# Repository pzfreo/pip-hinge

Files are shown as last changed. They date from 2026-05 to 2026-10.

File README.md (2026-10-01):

# pip-hinge

A parametric print-in-place piano hinge in [build123d](https://github.com/gumyr/build123d),
designed for clamshell cases.

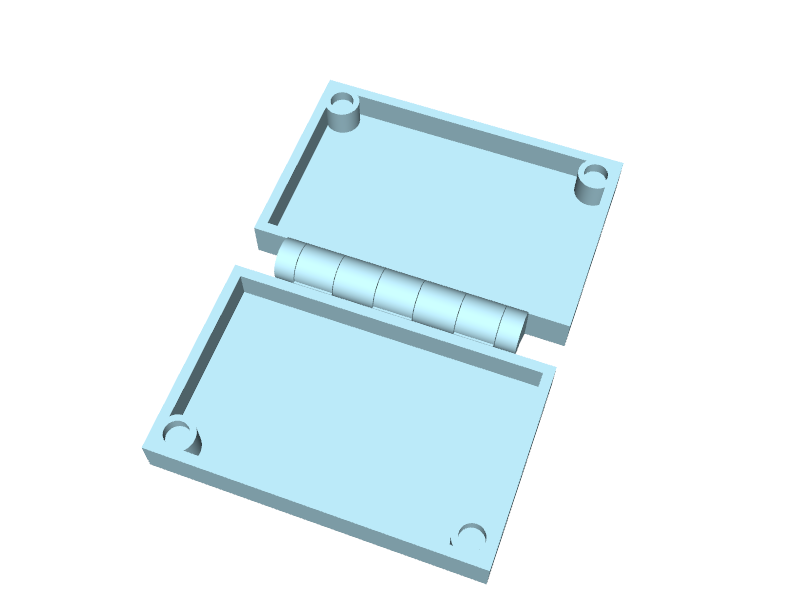
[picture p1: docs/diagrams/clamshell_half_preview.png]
clamshell with HALF knuckle and corner magnet pockets, flat-open print orientation


Start with four main inputs; the [parameter table](#parameters) covers the remaining fit and geometry controls.

```python
from pip_hinge import Knuckle, PinStyle, PrintInPlaceHinge

hinge = PrintInPlaceHinge(
    case_h        = 10,             # case wall height (mm)
    hinge_length  = 60,             # total hinge length along the axis (mm)
    stations      = 6,              # alternating tab count (even, ≥ 2)
    knuckle       = Knuckle.FULL,   # FULL = "bump on top", no ramp needed
)
base_leaf, lid_leaf = hinge.cylinder_side, hinge.pin_side
```

The default pin has 45° conical tips. Choose `PinStyle.ROUNDED` or the
experimental `PinStyle.BRIDGED` with the `pin_style` argument when needed.

`PrintInPlaceHinge` is a build123d `Compound` with two labelled children,
one per leaf:

- **`cylinder_side`** — the leaf whose knuckle tabs carry the bores;
- **`pin_side`** — the leaf with the end caps and the captured pin.

(Internally these are abbreviated *cs* and *ps*.) Each child is a `Compound`,
because a bare leaf can be several solids — see `mounting_flat` below.

`make_hinge(HingeParams(...))` builds the same thing from a reusable
parameter value.

### Where the hinge comes out

The hinge is built flat-open, in print orientation, ready to fuse into a case
whose walls stand on the bed:

- bed at **Z = 0**, wall top at **Z = `case_h`**;
- hinge axis along **Y** through X = 0, Z = `case_h + pivot_z_offset`;
- `cylinder_side` reaches X = +`hinge.leaf_width`, `pin_side` X = −`hinge.leaf_width`
  — those outer faces are where the two case back walls go;
- Y spans ±`hinge_length / 2`.

So for a base whose back wall's outer face is at X = x0, place the leaves
(build123d children are relative to their parent, so move the leaves
themselves, not the hinge):

```python
from build123d import Pos

at = Pos(x0 - hinge.leaf_width, y_centre, 0)
base = base + at * hinge.cylinder_side
lid = lid + at * hinge.pin_side
```

### Joints

`cylinder_side.joints["pivot"]` is a `RevoluteJoint` on the hinge axis and
`pin_side.joints["pivot"]` a matching `RigidJoint`, so the hinge can be swung
in an assembly view (0° = flat-open as printed, 180° = closed):

```python
hinge.cylinder_side.joints["pivot"].connect_to(hinge.pin_side.joints["pivot"], angle=180)
```

Each leaf also has a `"mount"` `RigidJoint` at the bottom centre of its outer
face (X = ±`leaf_width`, Y = 0, Z = 0), axes aligned with the hinge frame. To
attach the hinge to a case wall with joints instead of `Pos`:

```python
from build123d import Location, RigidJoint

RigidJoint("hinge", base, Location((x0, y_centre, 0)))    # back-wall outer face, bottom centre
base.joints["hinge"].connect_to(hinge.cylinder_side.joints["mount"])
hinge.cylinder_side.joints["pivot"].connect_to(hinge.pin_side.joints["pivot"], angle=0)
base = base + hinge.cylinder_side                         # leaves are now in place
lid = lid + hinge.pin_side
```

## In context: a flat-open clamshell with HALF knuckle

Built by [`examples/clamshell.py`](https://github.com/pzfreo/pip-hinge/blob/main/examples/clamshell.py) — case_h = 10mm,
80 × 50 mm footprint, 60 mm hinge with `Knuckle.HALF`, plus four 6 × 3 mm
corner magnet pockets to latch the case shut. Both halves print as one
piece in the orientation shown. The example also emits a bare HALF/FULL
variant (no magnets) for reference.

## Quick start

Install version **0.3.0** from [PyPI](https://pypi.org/project/pip-hinge/)
with `uv add "pip-hinge>=0.3.0"`. Earlier releases do not include `PinStyle`
or `FitProfile`. In a checkout, install it for development with:

```bash
uv venv
uv pip install -e .
```

Then in your build123d code:

```python
from pip_hinge import Knuckle, PrintInPlaceHinge

hinge = PrintInPlaceHinge(case_h=10, hinge_length=60, knuckle=Knuckle.FULL)
base = my_base + hinge.cylinder_side
lid = my_lid + hinge.pin_side
```

To run the included examples from a checkout:

```bash
uv run python examples/clamshell.py          # writes clamshell_{full,half,small,magnets}.{step,stl}
uv run python examples/hinge_only.py         # writes the bare hinge_{full,half}.{step,stl}
uv run python examples/conical_test_print.py --fit tighter  # two-size print plate with tighter fit
```

## Geometry at a glance

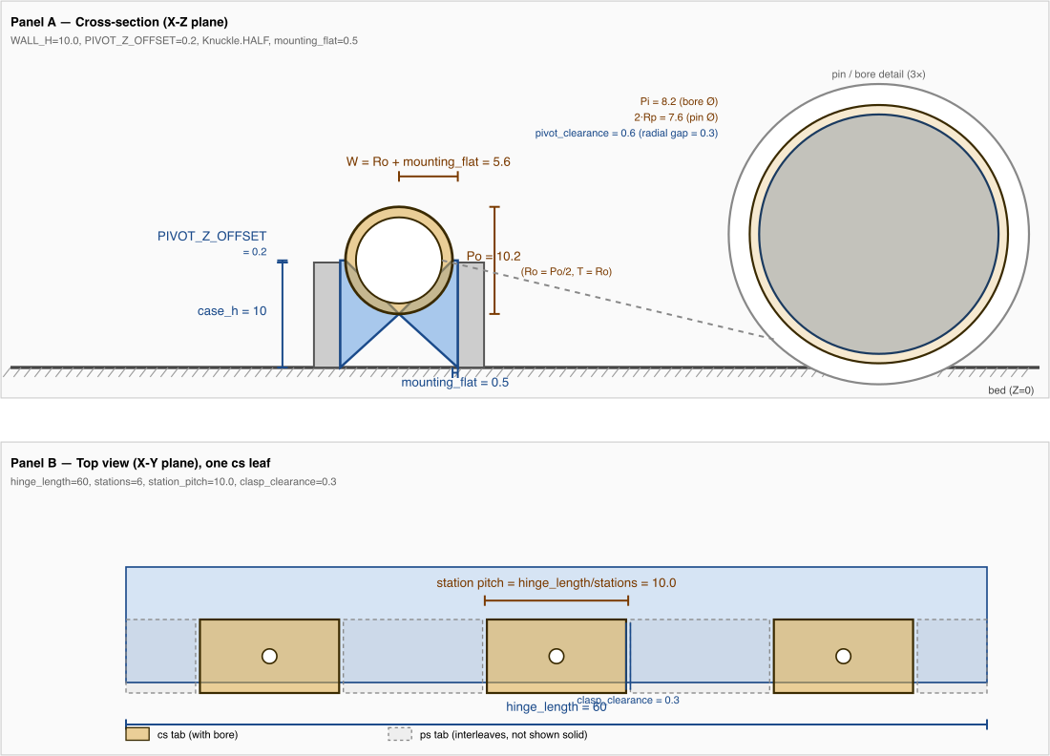
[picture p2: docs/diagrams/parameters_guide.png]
parameters guide


Cross-section (Panel A) shows the spatial parameters: `case_h` (wall
height), `pivot_z_offset` (extra lift), `mounting_flat` (flat past the
disc edge), plus the derived `Po`/`Ro`/`T`/`W` and the pin/bore inset.
Top view (Panel B) shows `hinge_length`, `stations`, derived
station pitch (`hinge_length / stations`), and `clasp_clearance` between tabs.

## Knuckle sizes

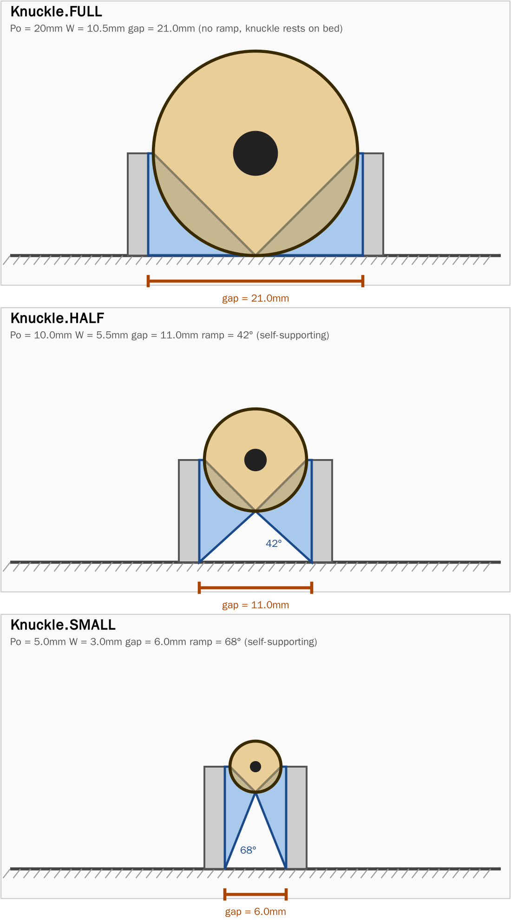
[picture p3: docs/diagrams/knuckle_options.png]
knuckle options


| `knuckle` | knuckle diameter | ramp | gap between case walls (flat-open) |
| --- | --- | --- | --- |
| `Knuckle.FULL` | `2 × (case_h + pivot_z_offset)` | none — rests on bed | `2 × (case_h + pivot_z_offset) + 2 × mounting_flat` |
| `Knuckle.HALF` | `case_h + pivot_z_offset` | 45° self-supporting teardrop | `case_h + pivot_z_offset + 2 × mounting_flat` |
| `Knuckle.SMALL`| `max((case_h + pivot_z_offset) / 2, 5 mm)` | ~25° from vertical (smaller knuckle → naturally steeper) | `max((case_h + pivot_z_offset) / 2, 5 mm) + 2 × mounting_flat` |

The knuckle diameter `Po` is sized to the lifted axis height
`case_h + pivot_z_offset`, and the flat-open gap between the case walls is
always `Po + 2 × mounting_flat` (= `2 × hinge.leaf_width`). For `case_h = 10`
with the defaults that is 21.4 mm (FULL), 11.2 mm (HALF) and 6.1 mm (SMALL).

See [docs/clamshell-integration.md](https://github.com/pzfreo/pip-hinge/blob/main/docs/clamshell-integration.md) for
mounting, orientation, multi-hinge layouts, and the closed-vs-open view.

## Parameters

The four primary inputs:

| Parameter | Default | Meaning |
| --- | --- | --- |
| `case_h` | (required) | Height in mm of the case wall each leaf attaches to |
| `hinge_length` | (required) | Total hinge length in mm along the rotation axis (Y) |
| `stations` | 6 | Even count of tab positions along Y, at least 2. Each end cap occupies half a position; 4, 6, 8, … are supported |
| `knuckle` | `Knuckle.FULL` | `FULL`, `HALF`, or `SMALL` — see the option table below |

`stations` counts alternating tab positions, not pin pairs or bored tabs.
For example, four stations make two bored cylinder-side tabs, one full
pin-side middle tab, and two half-width pin-side end caps. Any even count of
at least two is accepted; the usable count also depends on tab width.

Fit and pin options:

| Parameter | Default | Meaning |
| --- | --- | --- |
| `pin_style` | `PinStyle.CONICAL` | `CONICAL`: 45° tapered pin tips in matching tapered bores; `ROUNDED`: original hemispherical tips in round bores; `BRIDGED`: one continuous cylindrical pin in a teardrop-roof bore. Both revised bores released in one small clamshell print; the bridged hinge rocked noticeably |
| `knuckle_wall` | `None`  | Radial material thickness around the bore at its widest round section. `None` gives CONICAL at least 1.0 mm of modeled wall and grows the pin where station spacing permits. BRIDGED preserves at least 1.0 mm above its higher roof. Check the actual perimeter count in your slicer; set a value in mm to override |
| `mounting_flat` | 0.5 | Width in mm of the flat leaf strip beyond the knuckle where the case wall joins. At or below the resolved `pivot_clearance` the bare leaf can contain separate solids that join when fused to the wall |
| `pivot_clearance` | `None`  | Difference in mm between bore and pin diameters at the straight shank. The gap there is half this value; CONICAL also keeps that gap normal to its sloped tip. `None` selects 0.6 mm with STANDARD or 0.4 mm for small conical hinges with TIGHT |
| `pivot_z_offset`  | 0.2 | Lift of the hinge axis above the wall top. When closed, the lid then rests `2 × pivot_z_offset` above the base instead of meeting it on a zero-tolerance plane, so a high spot along the seam can't spring the front of the case open. Only the knuckle is raised — the leaves stay flush with the wall top. `0` disables it; must be less than the knuckle radius |
| `clasp_clearance` | `None`  | Gap in mm along Y between neighbouring tab faces. `None` selects the fit profile's value; an explicit value overrides it |
| `fit_profile` | `FitProfile.STANDARD` | `STANDARD` retains 0.3 mm radial and axial gaps. `TIGHT` gives small conical hinges the narrower gaps that worked in the earlier cylindrical-bore and the small shaped-bore trial |

### Tighter fit for small conical hinges

The [two-size conical test plate](https://github.com/pzfreo/pip-hinge/blob/main/examples/test_prints/README.md) printed and
released with the standard 0.3 mm gaps, but both lids rocked around the pin
and the smaller case also slid along the hinge axis. The
[tighter trial](https://github.com/pzfreo/pip-hinge/blob/main/examples/test_prints/tighter_fit/README.md) printed well on that
printer. Both printed plates used the earlier cylindrical bore. The
[new shaped-bore trial](examples/test_prints/shaped_bore_trial/README.md)
also released and felt good on that printer. Select the tighter gap values with:

```python
from pip_hinge import FitProfile, Knuckle, PrintInPlaceHinge

hinge = PrintInPlaceHinge(
    case_h=6, hinge_length=24, stations=4, knuckle=Knuckle.SMALL,
    fit_profile=FitProfile.TIGHT,
)
```

| Profile and geometry | Radial pin gap | Axial tab gap |
| --- | ---: | ---: |
| `STANDARD` (all hinges) | 0.3 mm | 0.3 mm |
| `TIGHT`: conical `SMALL`, barrel diameter ≤ 5.5 mm, station pitch ≤ 6 mm | 0.2 mm | 0.2 mm |
| `TIGHT`: conical `SMALL`, barrel diameter ≤ 5.5 mm, station pitch > 6 mm | 0.2 mm | 0.3 mm |
| `TIGHT`: other geometry | 0.3 mm | 0.3 mm |

Station pitch is `hinge_length / stations`. The straight-shank radial gap and
conical-tip normal gap are half of `pivot_clearance`, so 0.2 mm means
`pivot_clearance=0.4`. Passing
`pivot_clearance` or `clasp_clearance` explicitly overrides that part of the
profile. Fit still depends on the printer, material, and slicer settings;
try a small test print before committing to a large case. The successful
prints reported here were made on one **Bambu Lab P1S**. Material, nozzle
diameter, line width, layer height, and slicer profile were not recorded.
These results do not establish separate clearance recommendations for 0.4 mm
and 0.6 mm nozzles; use the [small Python trial](examples/shaped_bore_pair.py)
to check a different setup.

### Pin shapes and print tradeoffs

`CONICAL` uses short 45° pin tips and matching tapered bores. The small
shaped-bore trial released and felt good in one print. `ROUNDED` preserves the older
hemispherical tips and cylindrical bores. `BRIDGED` runs one continuous pin
through the whole hinge, which can resist pulling the leaves apart along the
axis, but its internal spans must print unsupported.

Conceptual conical, rounded, and bridged pin and bore sections

Cutaway of a continuous bridged pin

`BRIDGED` makes the printer span each bored tab with an unsupported pin.
The unsupported distance is approximately `hinge_length / stations +
clasp_clearance`: 5.3 mm for a 20 mm hinge with 4 stations, or 10.3 mm at
the 60 mm, 6-station defaults. The default `pivot_clearance` leaves only
0.3 mm of radial space between the printed pin and bore. Sagging plastic
can use up that space and fuse the hinge, even when the CAD solids are
separate. A tester reported that the earlier round bore roof settled onto
the pin and fused. The revised 45° teardrop roof released in one small
clamshell print, but that hinge was very loose and rocked around its pin.
In that size, the pointed roof leaves about 0.74 mm of modeled space above
the pin at its peak, even though the gap at the round sides is 0.3 mm.
The conical hinge from the same print felt much better. Check in the slicer
that the unsupported pin spans use bridge settings. Treat `BRIDGED` as an
experimental option when a continuous pin is needed; do not assume its
printed fit will match the conical hinge.

`ROUNDED` preserves the older pin and bore sizing. On a large barrel with
closely spaced stations, neighbouring rounded tips can meet inside a bore;
the library warns because the joined span may sag or fuse during printing.
The default `CONICAL` profile keeps an axial gap between its tips.

For 4 or more stations, the two middle tab types have the same width,
`hinge_length / stations − clasp_clearance`. Each end cap has half that width.
For example, a 20 mm hinge with 4 stations and the default gap has two
4.7 mm cylinder-side tabs, one 4.7 mm pin-side middle tab, and two 2.35 mm
end caps. The pin shank and tips extend into the bores beyond the middle
tab; that visible pin is wider than the tab itself.

The *shank* is the constant-diameter part of a pin between its pin-side tab
and its tapered or rounded tip. Three advanced settings change the shanks of
the `CONICAL` and `ROUNDED` pins. `pin_cyl_extra` adds to the station width to
give the middle shank length; it protrudes
`(pin_cyl_extra + clasp_clearance) / 2` past each
middle tab face. `pin_end_offset` sets how far an end shank protrudes past its
end cap face; its reach into the next bored tab is that value minus
`clasp_clearance`. `pin_short_cyl_factor × (hinge_length / stations)` is
the total end shank length, including the portion buried in the cap. These
settings do not affect the continuous `BRIDGED` pin. That pin runs the full
`hinge_length`; a shorter bridged pin is not currently parameterized.

### Geometry changes in 0.3

The default pin is now conical, with a matching tapered bore. It can use a wider bore than the original
rounded pin when station spacing leaves room for separate 45° tips; on
shorter hinges it uses a smaller bore to prevent those tips from joining.
`PinStyle.ROUNDED` retains the original pin tip profile and cylindrical bore.
The STANDARD tab gap is 0.3 mm measured between faces, with equal-width
middle tabs on both sides. Re-export existing designs and check the pin and
tab fit before relying on an older printed part.

## Validation

`PrintInPlaceHinge` / `make_hinge()` raise `ValueError` for hard geometric problems:
- non-positive `case_h`, `hinge_length`, or `mounting_flat`
- `stations < 2` or odd
- negative `pivot_z_offset`, or one not smaller than the knuckle radius
- bore Ø ≤ `pivot_clearance` (knuckle too small for the pivot clearance)
- `knuckle_wall` outside the knuckle radius
- invalid `pin_style` or clearances that leave no tab or pin material

And warns (`warnings.warn`) when:
- tab width `hinge_length / stations − clasp_clearance` drops below ~3 mm (too thin for FDM)

## Printing

Lay flat on the bed with the hinge axis along Y (parallel to bed).
Start with 0.2 mm layers and the part-cooling fan on. If adhesion needs a
brim, keep it clear of the hinge gaps. After printing, gently flex the leaves
to break the clearance gaps free.

For a first fit check of the current conical bore, use the
[small shaped-bore trial](examples/test_prints/shaped_bore_trial/README.md).
The [paired Python example](examples/shaped_bore_pair.py) generates the
conical and bridged cases used in the printed comparison and accepts gap
overrides for printer calibration.
The [earlier two-size plate](https://github.com/pzfreo/pip-hinge/blob/main/examples/test_prints/README.md)
documents the cylindrical-bore prints and their fit results.

- **FULL** knuckle body rests on the bed without supports. The optional
  `BRIDGED` pin still requires an unsupported bridge through each bore.
- **HALF** knuckle body has a self-supporting underside on valid sizes: it
  meets the disc tangentially at 45° and runs to the bed as a teardrop.
  The optional `BRIDGED` pin still needs a bridge test.

## How this was built

The build123d code, API design discussions, station-count generalisation,
self-supporting ramp, clamshell example, and documentation in this
repository were produced through a paired design session with
[Claude Code](https://claude.com/claude-code) (Anthropic's Claude Opus 4.7).
I drove the design decisions — what the API should look like, which
knuckle geometries to support, what trade-offs to accept — and Claude wrote
the code, generated the diagrams, ran the verifications, and opened the
PRs. The conversation is the source of truth for *why* the code looks the
way it does; the commit history reflects the steps.

The original FreeCAD geometry from r0berts provided the dimensional
starting point. The current pin profiles and fit defaults also include
changes described above. The Claude
collaboration is on the build123d port and the case-designer-facing API
built on top of it.

## Provenance

This is a port of **["Parametric print-in-place hinge. FreeCAD."](https://www.printables.com/model/1395662-parametric-print-in-place-hinge-freecad)**
by **[r0berts](https://www.printables.com/@r0berts_1183620)** on Printables,
licensed [CC BY 4.0](https://creativecommons.org/licenses/by/4.0/).

The original is a spreadsheet-driven FreeCAD model. This repository:

1. Translates the FreeCAD geometry into build123d Python via
   [fcd2b123d](https://github.com/pzfreo/fcd2b123d).
2. Reparameterises around four case-designer-facing inputs (`case_h`,
   `hinge_length`, `stations`, `knuckle`) with the original dimensional
   relationships derived under the hood.
3. Generalises the comb pattern (hardcoded 6 stations in the original) to
   any even number of stations ≥ 2, adds optional `Knuckle.HALF` and
   `Knuckle.SMALL` modes, and offers three pin profiles.

Per the CC BY 4.0 terms: design and dimensional relationships are
r0berts'; modifications are the build123d port, the four-input API, the
configurable station count, knuckle sizes, pin profiles, and fit defaults.
The original model's printer settings and extent of physical testing are
not documented in this repository.

## License

This work is licensed under [Creative Commons Attribution 4.0 International (CC BY 4.0)](https://creativecommons.org/licenses/by/4.0/),
matching the upstream Printables source. See [LICENSE](https://github.com/pzfreo/pip-hinge/blob/main/LICENSE).

When using or redistributing, please credit:

- **r0berts** — original FreeCAD design ([Printables](https://www.printables.com/model/1395662-parametric-print-in-place-hinge-freecad))
- **Paul Fremantle** (pzfreo) — build123d port, four-input parameterisation, station generalisation, and ramp option

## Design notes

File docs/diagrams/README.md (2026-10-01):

# Diagrams

Figures used in `docs/clamshell-integration.md` and the project README.
`pin_profiles.svg` compares the three pin and bore sections;
`bridged_pin.svg` shows the continuous pin along the hinge axis.

## Geometry diagrams (SVG → PNG)

```bash
python docs/diagrams/render_options.py        # → knuckle_options.svg
python docs/diagrams/render_closed_vs_open.py # → closed_vs_open.svg
python docs/diagrams/render_params.py         # → parameters_guide.svg
```

PNGs (used by markdown viewers that don't render SVG inline) via cairosvg:

```bash
uv run --with cairosvg python -c "
import cairosvg
for n in ['knuckle_options', 'closed_vs_open', 'parameters_guide']:
    cairosvg.svg2png(url=f'docs/diagrams/{n}.svg',
                     write_to=f'docs/diagrams/{n}.png',
                     output_width=1100)
"
```

## 3D model preview (clamshell_half_preview.png)

Rendered via [`build123d-mcp`](https://github.com/pzfreo/build123d-mcp)'s
`render_view` tool from the model in `examples/clamshell_magnets.step`:

```text
import_cad_file("examples/clamshell_magnets.step", "case")
render_view(objects="case", quality="high", azimuth=-25, elevation=25,
            save_to="docs/diagrams/clamshell_half_preview.png")
```

The MCP path uses VTK for clean shading; the equivalent matplotlib path
produces visible triangulation artifacts on curved surfaces, which is why
we use the MCP renderer instead.

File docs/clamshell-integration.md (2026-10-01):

# Integrating pip-hinge into a clamshell case

A practical guide for case designers who want to add a print-in-place piano
hinge to their build123d clamshell design.

## Scope

This guide covers symmetric clamshell cases (lid and base the same height),
printed as a single piece with the hinge already attached. The hinge is
treated as a separate piano hinge fused to the case back wall — not as the
case wall itself.

## The four inputs

```python
from pip_hinge import Knuckle, PinStyle, PrintInPlaceHinge

hinge = PrintInPlaceHinge(
    case_h        = 10,             # case wall height (mm)
    hinge_length  = 60,             # total hinge length along its axis (mm)
    stations      = 6,              # alternating tab count (even, ≥ 2)
    knuckle       = Knuckle.FULL,   # FULL = no ramp; HALF = 45° self-supporting ramp
)
cylinder_side, pin_side = hinge.cylinder_side, hinge.pin_side
```

Knuckle diameter, leaf width, and pin radius are derived from the first four
inputs. The conical pin is the default; choose `PinStyle.ROUNDED` for the
original hemispherical tips, or `PinStyle.BRIDGED` for one continuous pin
through every bored tab. `BRIDGED` is experimental: bridge sag can fuse the
pin to the bore despite the modeled clearance. Its revised teardrop roof
released in one small clamshell print, but that hinge rocked and felt much
looser than the conical one. These observations came from one Bambu Lab P1S;
other printer and nozzle combinations have not been validated. See the
[print trial](../examples/test_prints/shaped_bore_trial/README.md) before
printing a complete case.

The conical default uses a bore that follows the shank and 45° tips. The
knuckle wall and station spacing limit its widest radius while keeping at
least 1.0 mm of modeled material and separate tips. Check the actual
perimeter count in your slicer;
`knuckle_wall` sets the thickness explicitly.

The fit controls are:
`mounting_flat` (default 0.5 mm of flat past the disc edge for case-wall
attachment and clearance from the rotating barrel — the cs body fragments into multiple solids at this size but
they fuse into the case wall, see "Common gotchas" below), `pivot_clearance`
(difference between pin and bore diameters at the shank; the radial gap there
and normal gap along conical tips are half of it),
and `clasp_clearance` (the gap along Y between neighbouring tabs). With the
default `FitProfile.STANDARD`, both radial and axial gaps are 0.3 mm. See the
[tight-fit rule](../README.md#tighter-fit-for-small-conical-hinges) for the
0.2 mm gap values tested on small conical hinges with both the earlier
cylindrical bore and the newer shaped bore.

## Knuckle sizes

FULL vs HALF cross-section

Both panels above use `case_h = 10mm`, `mounting_flat = 0.5mm` (the default).

The knuckle is sized to the lifted axis height `case_h + pivot_z_offset`
(0.2 mm by default), and in every mode the flat-open gap between the case
walls is `Po + 2 × mounting_flat` (= `2 × hinge.leaf_width`).

### Knuckle.FULL  (Po = 2 × (case_h + pivot_z_offset))

The original print-in-place design. The knuckle diameter equals the full
closed-case height (lid + base stacked). When flat-open for printing, the
knuckle's bottom rests directly on the bed — no ramp, no support needed.
When closed, the back of the case shows a clean half-D bulge of full
case height.

Geometric properties:
- Knuckle protrudes `case_h + 2 × pivot_z_offset` *above* the wall top (the "bump on top").
- Gap between case walls when flat-open: `2 × (case_h + pivot_z_offset) + 2 × mounting_flat`.
- Leaf paddle bottom is on the bed; the leaf is a tall rectangle.

### Knuckle.HALF  (Po = case_h + pivot_z_offset)

A more compact knuckle, diameter equal to a single wall's height. Sits
mostly above the wall top, with the lower half overhanging into the gap.
A 45°-or-shallower ramp on each leaf supports the knuckle from below as
the print rises — the two leaves' ramps converge at the knuckle bottom.

Geometric properties:
- Knuckle protrudes `(case_h + pivot_z_offset) / 2 + pivot_z_offset` above the wall.
- Gap between case walls when flat-open: `case_h + pivot_z_offset + 2 × mounting_flat`.
- Leaf has a sloped lower-inner face (the ramp).

### Knuckle.SMALL  (Po = max((case_h + pivot_z_offset) / 2, 5 mm))

The smallest knuckle the geometry will produce: 1/4 of FULL with a 5 mm
absolute floor that keeps the bore + pin big enough to print reliably on
a 0.4 mm-nozzle FDM regardless of case height. For `case_h ≥ 10 mm` the
1/4-of-FULL ratio dominates; below that, the 5 mm floor kicks in.

Geometric properties:
- Knuckle protrudes `Po / 2 + pivot_z_offset` above the wall.
- Gap between case walls when flat-open: `max((case_h + pivot_z_offset) / 2, 5 mm) + 2 × mounting_flat`.
- Ramp **steeper** than HALF's at the same `mounting_flat`. Counterintuitive
  but true: a smaller knuckle puts the disc bottom higher above the bed,
  so the leaf's ramp (from outer-bottom corner to disc bottom) rises more
  per unit of horizontal travel. At default `mounting_flat = 0.5 mm`, the
  ramp sits at ~22° from vertical — comfortably self-supporting (versus
  HALF at ~48° which works in practice but is at the FDM-cooling limit).
- With the standard conical fit, the pin diameter for `case_h = 10 mm` is
  2.5 mm. The 5 mm floor preserves room for a printable bore wall on
  smaller cases.
- `FitProfile.STANDARD` uses a 0.3 mm gap between neighbouring tabs. Use
  `FitProfile.TIGHT` for the tested small conical sizes, or set
  `clasp_clearance` explicitly for your printer's fit.

## Closed vs flat-open

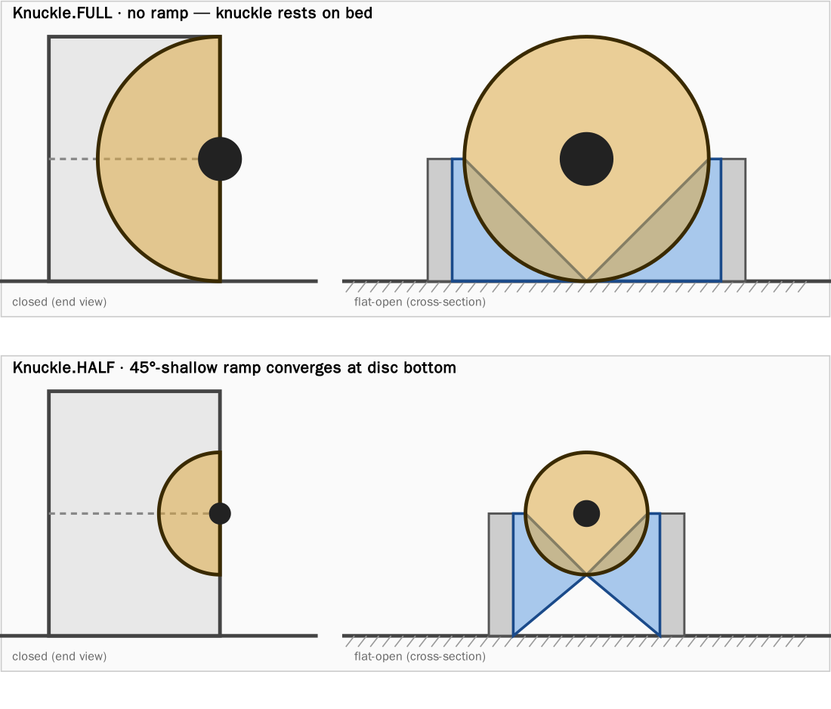
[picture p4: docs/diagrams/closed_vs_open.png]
closed and flat-open views


The closed-case profile shows the D-shaped bulge at the back. When flat-open
for printing, the same knuckle sits at axis
`Z = case_h + pivot_z_offset`, with the leaves extending from the axis down to
the bed.

## Coordinate convention

`PrintInPlaceHinge` comes out already placed for a flat-open case whose walls
stand on the bed:

- Bed at `Z = 0`; leaf tops flush with the wall top at `Z = case_h`.
- Hinge axis runs along **Y** through `(X = 0, Z = case_h + pivot_z_offset)`
  (`hinge.axis_z`).
- `cylinder_side` leaf extends to `X = +hinge.leaf_width`, `pin_side` to
  `X = −hinge.leaf_width`; the case back walls butt against these faces.
- Knuckle is centred on the axis, radius `Po/2`.
- Y range: `[−hinge_length/2, +hinge_length/2]`.

To put the hinge against a base whose back-wall outer face is at `X = x0`,
move the leaves (children are relative to their parent in build123d, so
moving the hinge itself does not move `hinge.cylinder_side`):

```python
from build123d import Pos

at = Pos(x0 - hinge.leaf_width, y_centre, 0)
base = base + at * hinge.cylinder_side
lid  = lid  + at * hinge.pin_side
```

## Stations

`stations` is the even number of tab positions along the rotation axis Y
(cs = cylinder side, ps = pin side). Two end caps each occupy half a
position. Any even count of at least 2 is accepted. Each full tab is
`hinge_length / stations - clasp_clearance` wide, so the STANDARD profile
leaves a 0.3 mm gap between neighbouring tab faces.

| stations | tabs | typical use |
| --- | --- | --- |
| 2 | 1 cs centred, 2 ps half-end-caps | tiny hinges (< 30mm)|
| 4 | 2 cs, 1 ps middle, 2 ps half-end-caps | small |
| 6 | 3 cs, 2 ps middle, 2 ps half-end-caps | default |
| 8, 10, … | scales up cleanly | long hinges |

Below a physical tab width of about 3 mm the tabs become thin for FDM
— a warning is emitted.

## One hinge or many?

Hinges do **not** need to run the entire case length. Multiple shorter
hinges along the back edge are usually better than one long one:

| Case back-edge length | Recommended hinges | Notes |
| --- | --- | --- |
| < 100 mm | 1 | Spans most or all of the back |
| 100–250 mm | 1 long or 2 shorter  | 2 shorter if the lid is heavy or thin |
| 250–450 mm | 2 | Position ~10–20 % in from each end |
| > 450 mm | 3+ | One centred, two ~15 % from the ends |

Multiple hinges **must be coaxial** — they all share the same hinge axis (Y
line). You position them at different Y offsets along that axis.

## Attaching the hinge to the case

Take the two leaves (`hinge.cylinder_side`, `hinge.pin_side`), position them on the case's back
edge, and boolean-union them into the case bodies.

For a clamshell with both halves coplanar on the bed during print:

```python
hinge = PrintInPlaceHinge(case_h=wall_h, hinge_length=back_edge_len,
                          knuckle=Knuckle.FULL)
base_body = base_body + hinge.cylinder_side
lid_body  = lid_body  + hinge.pin_side
```

If your assembly already uses build123d joints, place the leaves through
their named `"mount"` and `"pivot"` joints. Here `x0` is the base back wall's
outer X face and `y_centre` is the hinge centre along that wall:

```python
from build123d import Location, RigidJoint

RigidJoint("hinge", base_body, Location((x0, y_centre, 0)))
base_body.joints["hinge"].connect_to(hinge.cylinder_side.joints["mount"])
hinge.cylinder_side.joints["pivot"].connect_to(
    hinge.pin_side.joints["pivot"], angle=0
)
base_body = base_body + hinge.cylinder_side
lid_body = lid_body + hinge.pin_side
```

The leaf's outer face (at `X = hinge.leaf_width`) is where the case wall attaches.
`mounting_flat` controls the flat strip of leaf material past the disc edge
that the wall actually glues / fuses to — 0.5 mm is the default and is
deliberately below the `pivot_clearance` so the cylinder-side leaf fragments at the
disc-edge level. Those fragments still share their outer face with the case
wall and fuse cleanly on boolean union. Increase `mounting_flat` for a
larger glue surface at the cost of a wider gap between case halves.

### Multi-hinge variant

```python
hinge = PrintInPlaceHinge(case_h=wall_h, hinge_length=50, knuckle=Knuckle.FULL)
for y_centre in [-100, 0, 100]:
    base = base + Pos(0, y_centre, 0) * hinge.cylinder_side
    lid  = lid  + Pos(0, y_centre, 0) * hinge.pin_side
```

All hinges sit on the same axis (`Z = wall_h + pivot_z_offset`), at different Y positions.

## Print orientation

The natural orientation is **flat-open**: lid and base coplanar on the bed,
walls extending up, hinge axis at the top of the back walls.

- **Knuckle.FULL**: knuckle bottom rests on the bed at `Z = 0` (since
  `Po = 2 × (case_h + pivot_z_offset)` and the axis is at
  `Z = case_h + pivot_z_offset`). The outer barrel needs no ramp. The
  optional BRIDGED pin still has unsupported spans inside the bores.
- **Knuckle.HALF**: knuckle bottom hovers at `Z = (case_h + pivot_z_offset) / 2`. The 45°
  ramps on each leaf converge at the knuckle bottom, supporting it from
  below. Prints supportless at any case size, but you need to choose
  `mounting_flat` small enough that the ramp angle stays ≤ 45°.

In both cases the case walls provide structural support below the outer
hinge body. The optional BRIDGED pin still needs a printer-specific bridge
test inside the bore.

## Opening angle

The hinge mechanism rotates freely 360°. What limits actual opening is the
**case geometry**:

| Setup | Max angle  |
| --- | --- |
| Hinge axis right at the back wall top, on a table | 180° |
| Hinge axis offset back by `mounting_flat + Ro` | ~270° |
| Case picked up off the table | 360° |

For a clamshell that lies flat-open on a table, 180° is the natural max.

## Sealing & closure fit

- **Same wall height**: the symmetric clamshell assumes lid and base walls
  are equal. They meet at the midplane of the assembled case.
- **Wall edge tolerance**: leave 0.1–0.2 mm clearance between mating wall
  edges so they don't bind. Add a small chamfer (0.5 mm) on the outer top
  edges of both halves to hide the seam.
- **Latch / catch**: the hinge holds the back; for the front to stay
  closed, add a friction tab, snap catch, or magnet pocket. (Out of scope
  for this doc.)

## Worked example: small box, 1 hinge

See [`examples/clamshell.py`](../examples/clamshell.py) for the full
runnable script — it builds the same 80 × 50 × 10 mm clamshell for both
`Knuckle.FULL` and `Knuckle.HALF`, exporting to
`examples/clamshell_full.{step,stl}` and `examples/clamshell_half.{step,stl}`.

Sketch:

```python
from build123d import Align, Box, Compound, export_stl
from pip_hinge import Knuckle, PrintInPlaceHinge

CASE_H, CASE_W, CASE_D, WALL_T = 10, 80, 50, 2.5

def hollow_half(x_sign, leaf_outer_x):
    """Open-top box; back wall sits at X = leaf_outer_x on the hinge side."""
    x_min = x_sign * leaf_outer_x if x_sign > 0 else x_sign * (leaf_outer_x + CASE_D)
    align = (Align.MIN, Align.CENTER, Align.MIN)
    outer = Box(CASE_D, CASE_W, CASE_H, align=align).translate((x_min, 0, 0))
    inner = Box(CASE_D - 2*WALL_T, CASE_W - 2*WALL_T, CASE_H - WALL_T,
                align=align).translate((x_min + WALL_T, 0, WALL_T))
    return outer - inner

# pivot_z_offset (default 0.2 mm) raises the axis above the wall top
hinge = PrintInPlaceHinge(case_h=CASE_H, hinge_length=64, knuckle=Knuckle.FULL)

base = hollow_half(+1, hinge.leaf_width) + hinge.cylinder_side
lid  = hollow_half(-1, hinge.leaf_width) + hinge.pin_side
export_stl(Compound([base, lid]), "clamshell.stl")
```

Three things easy to get wrong:

- The case back wall sits at **X = `hinge.leaf_width`** (= `Ro + mounting_flat`),
  not at the hinge axis. The wall's inner face attaches to the leaf's outer face there.
- `base + lid` returns a `ShapeList` (one-shot boolean), not a `Compound` of
  two bodies. Wrap with `Compound([base, lid])` to keep them as separate
  print-in-place bodies.
- Pass the real wall height as `case_h` and leave `pivot_z_offset` to do
  the lift. Without the offset, the lid and base wall tops meet on a
  0-tolerance plane and any high spot anywhere along the seam springs the
  front jaw open by ~1 mm. The knuckle is sized to the lifted axis, so at
  `Knuckle.FULL` it still rests on the bed. Add corner magnet pockets
  if you want a positive latch (see `examples/clamshell.py`).

## Worked example: long box, 3 hinges

```python
case_w = 400
hinge_len_each = 60
hinge_y_centres = [-150, 0, 150]

base, lid = base_blank, lid_blank
hinge = PrintInPlaceHinge(case_h=wall_h, hinge_length=hinge_len_each,
                          knuckle=Knuckle.FULL)
for yc in hinge_y_centres:
    base = base + Pos(0, yc, 0) * hinge.cylinder_side
    lid  = lid  + Pos(0, yc, 0) * hinge.pin_side
```

The case back walls run continuously the full 400 mm; only the hinges are
segmented.

## Common gotchas

- **Wrong case_h**: `case_h` is the *wall height* of one case half, not the
  combined closed-case height. At FULL the knuckle works out to
  `2 × (case_h + pivot_z_offset)` in diameter — about twice the wall.
- **Too many stations**: doubling stations halves the station pitch. A tab
  width below ~3 mm may print poorly on FDM (a warning fires). For long hinges, keep
  stations at 6–10 and scale `hinge_length` instead.
- **Very small HALF knuckles**: as `case_h` shrinks, the bore can become too
  small for `pivot_clearance`; the constructor raises a clear error. Choose
  SMALL (with its 5 mm diameter floor) or FULL for tiny cases.
- **Increasing mounting_flat for HALF**: bigger mounting_flat means
  shallower ramp (still self-supporting). But the gap between case halves
  also grows. 1–2 mm is usually plenty for fusion.
- **Reducing mounting_flat below pivot_clearance**: at very small
  `mounting_flat` (< the resolved `pivot_clearance`, 0.6 mm with STANDARD)
  the leaf strip at X ∈ [Ro+Pc, W] collapses to zero/negative width — the bare hinge
  then comes back as N/2 + ~N/2 fragmented solids instead of 2.
  This is fine **as long as you fuse the hinge into a case**: each
  fragment shares its outer face with the case wall and fuses with it on
  boolean union. The case wall plays the role of the vanished leaf strip.
  `hinge.cylinder_side` / `hinge.pin_side` keep the fragments grouped by
  leaf, so you never need to sort `hinge.solids()` yourself.
- **Setting pivot_z_offset to 0**: gives zero design tolerance at the
  closed seam — any printed high spot then opens the front jaw. The 0.2 mm
  default (0.4 mm closed-case back gap) is a good starting point; magnets
  or finger pressure overcome that easily, and the case stops resting
  slightly open.

## Quick reference

For most clamshell cases:

```python
from pip_hinge import FitProfile, Knuckle, PinStyle, PrintInPlaceHinge

PrintInPlaceHinge(
    case_h          = wall_h,            # case wall height
    hinge_length    = back_edge_length,  # total length along the hinge axis
    stations        = 6,                 # default
    knuckle         = Knuckle.FULL,      # or HALF for a more compact knuckle
    pin_style       = PinStyle.CONICAL,  # 45-degree tips; ROUNDED or BRIDGED available
    mounting_flat   = 0.5,               # mm of flat past the disc for fusion (default)
    fit_profile     = FitProfile.STANDARD, # default; TIGHT for tested small conical hinges
    pivot_clearance = None,              # select from fit_profile; 0.6 here
    pivot_z_offset  = 0.2,               # default — axis lift above the wall top
    clasp_clearance = None,              # select from fit_profile; 0.3 here
)
```

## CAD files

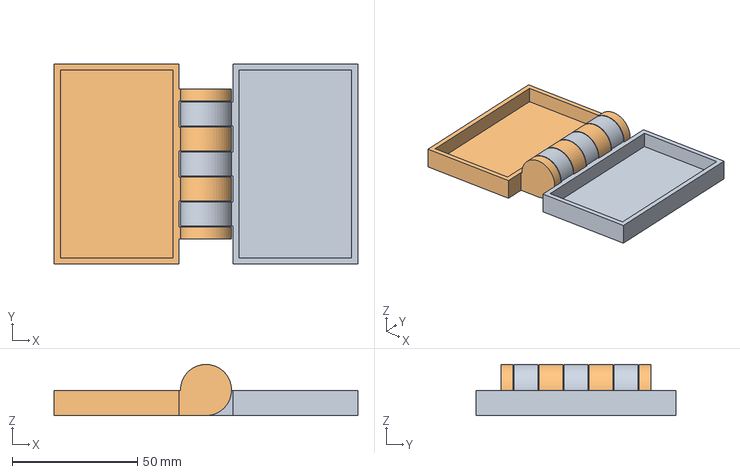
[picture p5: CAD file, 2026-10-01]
examples/clamshell_full.step
121.4 x 80.0 x 20.4 mm

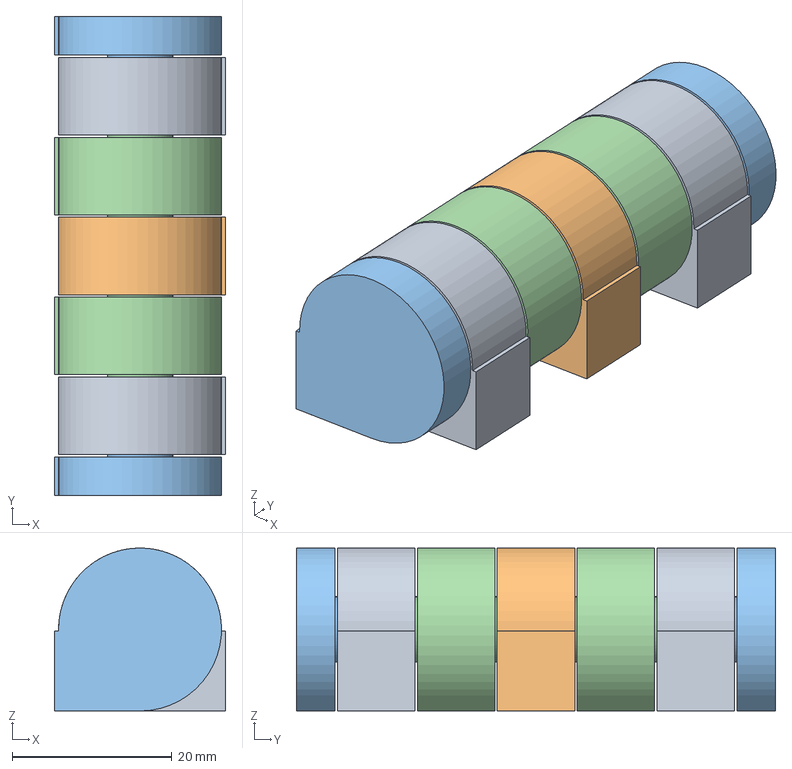
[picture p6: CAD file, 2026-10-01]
examples/hinge_full.step
21.4 x 60.0 x 20.4 mm
cylinder_side
pin_side

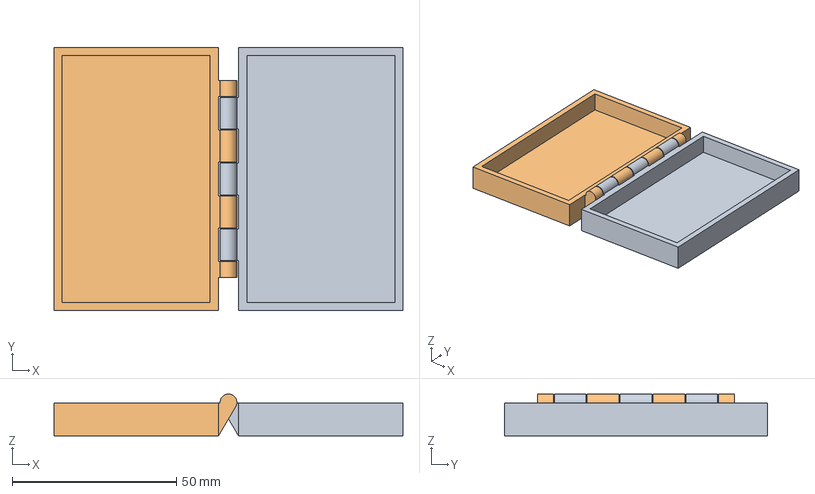
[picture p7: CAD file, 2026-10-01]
examples/clamshell_small.step
106.1 x 80.0 x 12.7 mm

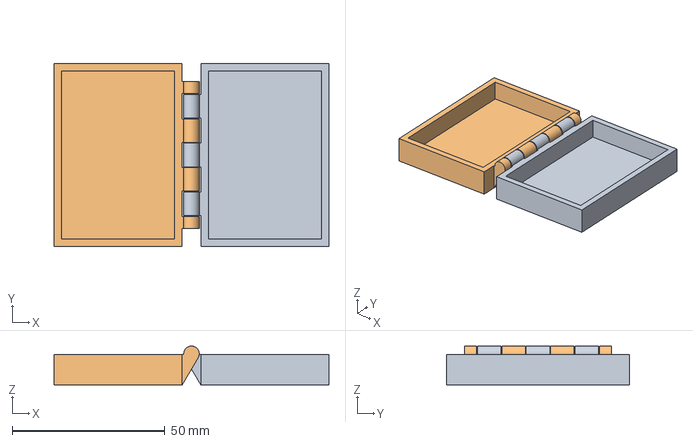
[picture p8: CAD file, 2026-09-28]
examples/test_prints/conical_clamshell_large.step
90.1 x 60.0 x 12.7 mm

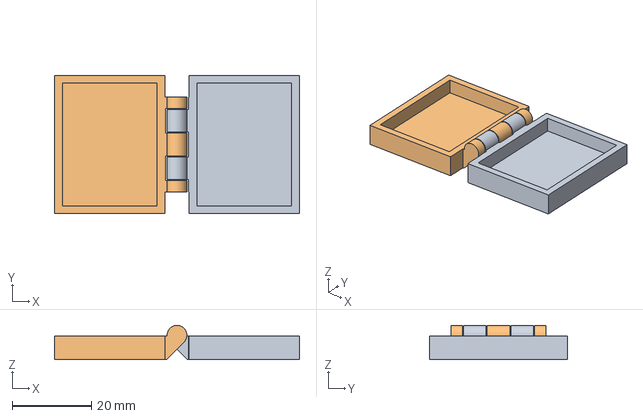
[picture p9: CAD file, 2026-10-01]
examples/test_prints/shaped_bore_trial/conical_shaped_bore_small.step
62.0 x 35.0 x 8.70 mm

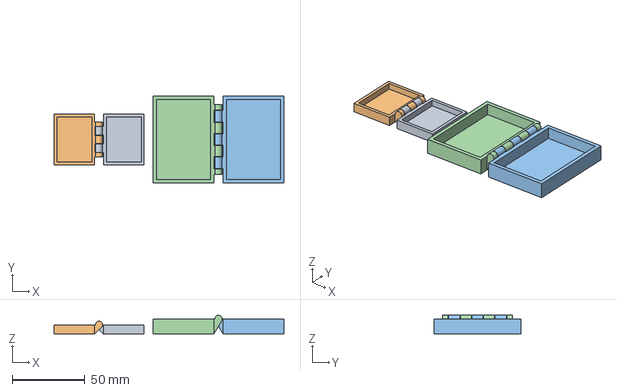
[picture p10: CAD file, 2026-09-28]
examples/test_prints/tighter_fit/conical_clamshell_pair.step
158.1 x 60.0 x 12.7 mm

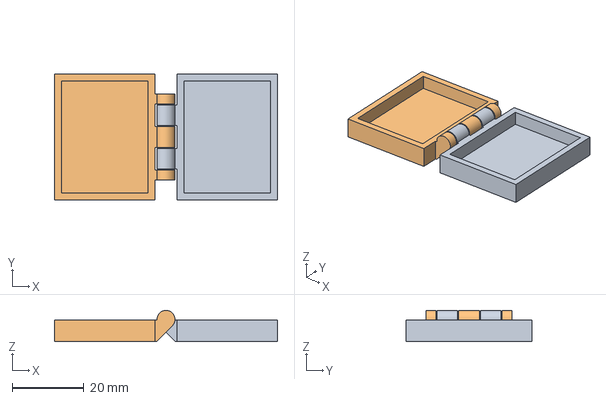
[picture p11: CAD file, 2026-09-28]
examples/test_prints/conical_clamshell_small.step
62.0 x 35.0 x 8.70 mm

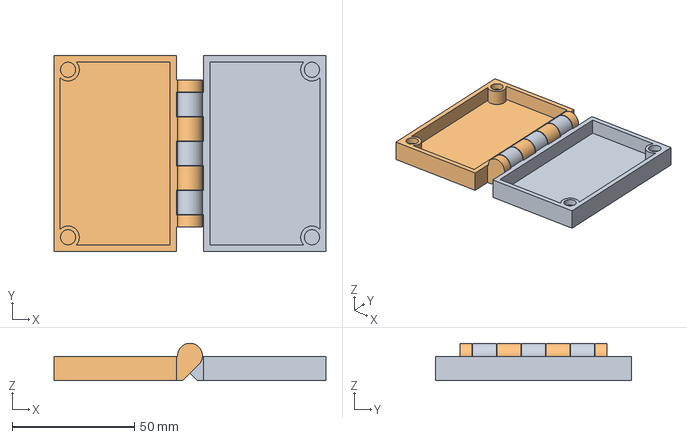
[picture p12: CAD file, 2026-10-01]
examples/clamshell_magnets.step
111.2 x 80.0 x 15.3 mm

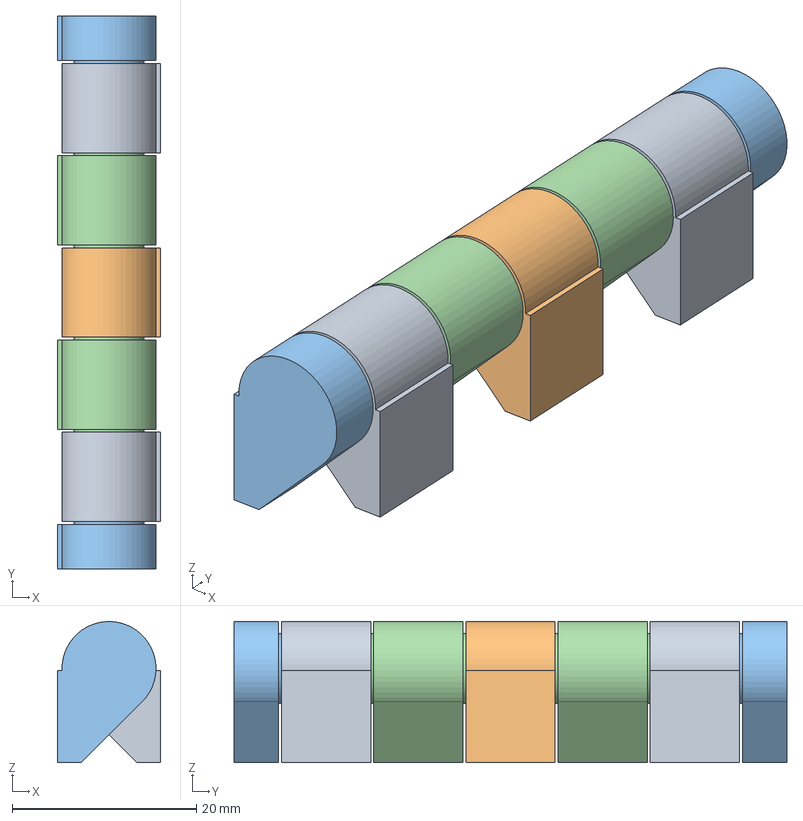
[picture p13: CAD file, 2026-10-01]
examples/hinge_half.step
11.2 x 60.0 x 15.3 mm
cylinder_side
pin_side

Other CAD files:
examples/test_prints/conical_clamshell_pair.step
examples/test_prints/tighter_fit/conical_clamshell_large.step
examples/test_prints/tighter_fit/conical_clamshell_small.step
examples/clamshell_half.step
examples/clamshell_full.stl
examples/clamshell_half.stl
examples/clamshell_magnets.stl
examples/clamshell_small.stl
examples/hinge_full.stl
examples/hinge_half.stl
examples/test_prints/conical_clamshell_large.stl
examples/test_prints/conical_clamshell_pair.stl
examples/test_prints/conical_clamshell_small.stl
examples/test_prints/shaped_bore_trial/conical_shaped_bore_small.stl
examples/test_prints/tighter_fit/conical_clamshell_large.stl
examples/test_prints/tighter_fit/conical_clamshell_pair.stl
examples/test_prints/tighter_fit/conical_clamshell_small.stl

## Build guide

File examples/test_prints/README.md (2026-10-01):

# Conical-pin clamshell test print

The [combined STL](conical_clamshell_pair.stl) contains two flat-open,
print-in-place clamshells, side by side with a 6 mm gap. Both use explicit
`PinStyle.CONICAL`, `Knuckle.SMALL`, and the library's default 0.3 mm axial
tab gap and 0.3 mm radial pin-to-bore gap.
The small knuckle is 5.0 mm in diameter on the smaller case and 5.1 mm on
the larger case.

Both cases have now been physically printed: the hinges released and worked,
but their rocking play was more than expected. The small case also slid along
the hinge axis. A [tighter fit trial](tighter_fit/README.md) subsequently
printed well: it reduces the radial pin gap on both cases and the axial tab
gap on the small case. Keep this original plate as the baseline for comparison.
These exported files retain the earlier cylindrical bore. The current code
uses a shaped conical bore; the [new small trial](shaped_bore_trial/README.md)
tested that change and printed well. The prints were on a **Bambu Lab P1S**.
The nozzle and layer values below are suggested starting settings, not a
record of the successful printer setup; material, nozzle diameter, line
width, layer height, and slicer profile were not captured.

| Case | Half footprint | Wall height | Hinge length | Stations | Flat-open footprint |
| --- | --- | ---: | ---: | ---: | --- |
| [Small](conical_clamshell_small.stl) | 35 × 28 mm | 6 mm | 24 mm | 4 | 62.0 × 35 mm |
| [Large](conical_clamshell_large.stl) | 60 × 42 mm | 10 mm | 48 mm | 6 | 90.1 × 60 mm |

The combined footprint is about **158.1 × 60 mm** before any brim. Import
the combined STL once, keep its open sides facing up and its flat bottoms on
the bed, and print without generated supports. Start at 0.2 mm layers with a
0.4 mm nozzle, and leave the slicer scale at 100%. Start without a brim; if
adhesion needs one, keep it at 2 mm or less and inspect the hinge gaps in the
slicer preview. The [STEP assembly](conical_clamshell_pair.step) is provided for CAD
inspection; use the STL for slicing.

After cooling, gently move each lid to free the print-in-place clearance.
Record whether each hinge releases, whether it rotates without binding, and
whether the lids close without a gap caused by the hinge. CAD checks cannot
predict all printer effects, so treat this as a fit test before printing a
larger case.

The command below exports the **current** geometry and will replace these
historical test files if run in this directory. To reproduce the original
exports exactly, run it from commit `502896f` instead.

From the repository root:

```bash
.venv/bin/python examples/conical_test_print.py
```

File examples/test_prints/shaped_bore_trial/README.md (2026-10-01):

# Shaped conical bore trial — printed

This small clamshell tests the revised conical bore. The bore follows the pin's
straight shank and 45° tip, leaving a 0.2 mm modeled gap normal to the cone.
The printed small case released and the hinge felt good. In the same print, a
small `BRIDGED` case with a teardrop-roof bore also released, but was very
loose and rocked around its pin. This is one print result, not a fit guarantee
for other sizes or printers. The [earlier tighter-fit
plate](../tighter_fit/README.md) also printed successfully; its
STL uses the original cylindrical bore and remains available for comparison.

The comparison used the same 24 mm, four-station SMALL hinge on both cases.
The conical case used `FitProfile.TIGHT` (0.2 mm radial and axial gaps); the
bridged case used `FitProfile.STANDARD` (0.3 mm radial and axial gaps). These
results came from one **Bambu Lab P1S**; material, nozzle diameter, line
width, layer height, and slicer profile were not recorded.
The teardrop roof leaves about 0.74 mm of modeled space above the bridged
pin at its peak, which helps explain the rocking despite the 0.3 mm gap at
the round sides.

The trial uses `Knuckle.SMALL`, a 24 mm hinge with four stations, and
`FitProfile.TIGHT`. Its case halves each measure 35 × 28 × 6 mm. Print the
[STL](conical_shaped_bore_small.stl) at 100% scale, flat on the bed with the
open sides up and generated supports off. Use a calibrated slicer profile;
the successful print does not establish nozzle-specific settings. Check the
bore and pin in the slicer preview before printing.
The [STEP file](conical_shaped_bore_small.step) is for CAD inspection.

In the slicer preview, check three regions before starting: the first-layer
gaps between moving parts must remain open; the conical tips must remain
separate inside each bored tab; and the bridged pin's unsupported spans must
use bridge toolpaths. The diagrams show CAD geometry, not actual slicer
toolpaths or measured prints.

After cooling, check that the hinge releases and rotates without binding.
Compare lid rocking and axial sliding against the earlier tighter-fit print.
Record printer, material, nozzle, line width, layer height, and slicer settings
alongside the result. A valid CAD clearance does not guarantee release.

Regenerate from the repository root:

```bash
python examples/conical_bore_trial.py
```

To reproduce **both** printed cases from Python, including the two dots that
mark the bridged base, run:

```bash
python examples/shaped_bore_pair.py
```

This writes individual STEP files and a 130 × 35 mm pair with a 6 mm gap in
the current directory: conical on the left, bridged on the right. The script
defaults to the printed gaps above; it does not change the library's default
fit settings.

If the pin fuses to its bore, try increasing only that case's radial gap by
0.05 mm, for example `--conical-radial-gap 0.25`. The script sets
`pivot_clearance` to twice the requested radial gap. If adjacent knuckle
faces fuse, increase that case's axial gap by 0.05–0.1 mm, for example
`--conical-axial-gap 0.25`. For the bridged case, inspect the unsupported
pin spans and bore roof in the slicer and check its bridge settings; more
clearance may release it but will add to its already noticeable play.
For a different printer or nozzle, treat these as starting CAD gaps and
calibrate with a small print. There is no validated 0.4 mm versus 0.6 mm
nozzle tolerance table from the available P1S prints.

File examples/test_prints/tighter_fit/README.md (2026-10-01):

# Tighter conical-hinge fit trial

This trial followed the [original plate](../README.md), which released but
had noticeable rocking around both pins. The small case also slid along the
hinge axis. Both tighter cases have now printed successfully. The
[combined STL](conical_clamshell_pair.stl) contains the same two case sizes,
both with `Knuckle.SMALL` and `PinStyle.CONICAL`. `pivot_clearance` changes
from 0.6 to 0.4 mm on both cases, so the modeled radial pin-to-bore gap
drops from 0.3 to **0.2 mm**. The small case's axial tab gap drops from
0.3 to **0.2 mm**; the large case keeps the proven **0.3 mm** axial gap.
These exported files use the earlier cylindrical bore. The current code
uses a shaped conical bore; the [new small trial](../shaped_bore_trial/README.md)
tested that change and also printed well. The successful prints were on a
**Bambu Lab P1S**; material, nozzle diameter, line width, layer height, and
slicer settings were not recorded.

| Case | Half footprint | Hinge length | Radial gap | Axial gap | Individual STL |
| --- | --- | ---: | ---: | ---: | --- |
| Small | 35 × 28 mm | 24 mm | 0.2 mm | 0.2 mm | [STL](conical_clamshell_small.stl) |
| Large | 60 × 42 mm | 48 mm | 0.2 mm | 0.3 mm | [STL](conical_clamshell_large.stl) |

The combined plate occupies about **158.1 × 60 mm** before any brim. To save
material, print the small case alone first. Keep the same material, slicer
settings, and orientation used for the original print; use 100% scale and no
generated supports. Inspect the pin gaps in the slicer preview. These two
prints supplied the evidence for `FitProfile.TIGHT`; try the small case first
when testing on a different printer.
The [combined STEP](conical_clamshell_pair.step) and individual STEP files
are for CAD inspection.

After cooling, compare the new small case against the original: does the
hinge release, rotate through its range without binding, and rock less when
the lid is lifted at its far edge? Check whether the small lid also slides
less along the hinge axis. A 0.2 mm modeled gap can still fuse on another
printer, so do not treat CAD validity or one successful setup as a guarantee.

The command below exports the **current** geometry and will replace these
historical test files if run in this directory. To reproduce the original
exports exactly, run it from commit `502896f` instead.

From the repository root:

```bash
.venv/bin/python examples/conical_test_print.py --fit tighter
```

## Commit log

2026-05-24 Initial: parametric print-in-place piano hinge
    Lifted from hinge-03.fcstd via fcd2b123d, with every sketch coordinate
    rewritten in terms of named HingeParams fields. No magic numbers in the
    geometry — all literals trace back to parameters or documented constants
    from the original FreeCAD design.
    Default parameters reproduce the hinge-03 geometry bit-for-bit:
    cylinder_side vol = 6060.7123 mm³ (matches FreeCAD reference)
    pin_side vol = 6728.8937 mm³ (matches FreeCAD reference)
    inter-leaf clearance = 0.3 mm everywhere (FDM print-in-place ready)
    Verified scaling works across:
    - 2× scale (80mm hinge)
    - chunky pivot (pivot_inner=8, larger pin/bore + thicker leaf)
    - tighter clas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
    [hinge_chunky.step, hinge_chunky.stl, hinge_default.step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]
2026-05-24 Add CC BY 4.0 license and attribution to r0berts
    The original design is "Parametric print-in-place hinge. FreeCAD."
    by r0berts on Printables (model 1395662), licensed CC BY 4.0. This
    build123d port is a derivative under the same license. Add LICENSE
    file with full attribution and update README + module docstring with
    the upstream link and credit.
2026-05-24 docs: clamshell-integration guide for case designers
    Covers sizing, single vs multiple coaxial hinges along the back edge,
    attachment via boolean fusion, print orientation, opening-angle limits,
    and worked examples for both small (1-hinge) and long (3-hinge) cases.
    Corrects an earlier mistaken assumption that a hinge must span the full
    case length — for longer cases, 2 or 3 shorter coaxial hinges are
    typically better than one long one (less warp risk during print, less
    inter-leaf fusion area, distributed load).
2026-05-25 Add self_support_ramp flag for clamshell flat-open printing (#1)
    * Add self_support_ramp flag for clamshell flat-open printing
    When a clamshell case lays the lid and base coplanar on the bed with
    the hinge between them, the knuckle becomes a horizontal cylinder
    whose bottom half overhangs into the gap. For small knuckles FDM
    bridges it cleanly; for larger ones or for reliable first-try prints,
    this is where supports start creeping in.
    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
2026-05-25 Replace HingeParams with four-input clamshell-focused API (#2)
    The previous API exposed the hinge's internal geometry parameters
    (hinge_height, hinge_width, hinge_thickness, pivot_inner, pivot_outer,
    clasp_width, ...), which is the right thing if you're building a
    standalone hinge but is too many knobs to reason about for the
    intended use case: bolting a print-in-place hinge to a clamshell.
    The new API takes four user-facing inputs:
    case_h case wall height (sets the hinge "scale")
    hinge_length total length along the hinge axis
    stations number of alternating cs/ps tabs (even, ≥ 2)
    knuckle Knuckle.FULL or Knuckle.HALF
    and derives everything else: knuckle diamete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
    [hinge_chunky.step, hinge_chunky.stl, hinge_default.step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]
2026-05-25 Add clamshell box examples + fix pocket polygon for small mounting_flat (#3)
    The new examples/clamshell.py builds a complete clamshell case (base + lid +
    integrated hinge) for both Knuckle.FULL and Knuckle.HALF, exporting STEP and
    STL. This is what users actually want as a worked example — the bare
    hinge_full/hinge_half files only demonstrate the hinge in isolation.
    Along the way, found and fixed a polygon-orientation bug in the cs pocket
    generator. The original FreeCAD code set Xo_cs (the pocket polygon's left
    edge) to Xi − W. At the original W=30 defaults, this gave Xo_cs ≈ −24,
    safely to the left of −Xi ≈ −6, so the tab-bypass jogs (which extend to
    −Xi) stayed inside the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
    [clamshell_full.step, clamshell_full.stl, clamshell_half.step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]
2026-05-25 docs: note Claude Code's role in the build123d port
    Adds a "How this was built" section between Printing and License,
    acknowledging that the API design discussions, code, diagrams, and
    docs in this repo were produced through a paired session with
    Claude Code. Reads as a credit, not a hand-off — design decisions
    were the user's; Claude wrote and verified the code.
2026-05-26 examples: pivot_z_offset=0.2 by default + magnet-pocket variant (#6)
    Print testing showed the bare-default clamshell rests slightly open with
    a ~1 mm front-jaw gap. Cause: lid and base wall tops meet on a
    zero-tolerance plane, so any high spot along the seam springs the case
    open under elastic tension. Raising the hinge axis 0.2 mm above the wall
    top gives a 2·δ = 0.4 mm intentional back gap that prevents incidental
    contact, and the case rests closed under its own tension.
    examples/clamshell.py
    - PIVOT_Z_OFFSET = 0.2 applied to all three exported variants
    - new add_corner_magnet_pockets() helper: cylindrical bosses pushed
    into the interior corners (tangent to the corner) s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
    [clamshell_full.step, clamshell_full.stl, clamshell_half.step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]
2026-05-26 Add Knuckle.SMALL — max(case_h/2, 5mm) (#7)
    * Add Knuckle.SMALL — max(case_h/2, 5mm), smallest reliably printable knuckle
    SMALL is 1/4 of FULL (Po = case_h/2) with a 5 mm absolute floor that keeps
    the bore + pin reliably printable on a 0.4 mm-nozzle FDM regardless of case
    height. For case_h ≥ 10 mm the 1/4 ratio dominates; below that, the floor
    kicks in (so a 5 mm-wall case still has a printable 5 mm-Ø knuckle).
    hinge.py
    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
    [clamshell_full.step, clamshell_full.stl, clamshell_half.stl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]
2026-05-26 clasp_clearance: size-aware default — 0.2 for SMALL, 0.4 for HALF/FULL (#8)
    Print test of clamshell_small showed too much axial play even though
    HALF/FULL with the same clearance feel fine. Reason: 0.4 mm gap is a
    larger fraction of the smaller hinge — the original r0berts FreeCAD
    design used 0.2 mm for the same reason.
    HingeParams.clasp_clearance is now Optional[float]; left as None
    (the default), _resolve() picks 0.2 for Knuckle.SMALL and 0.4 for
    HALF/FULL. Pass an explicit value to override either way (e.g. if a
    particular printer can't hold 0.2 mm without the tabs fusing, or if
    you want HALF tightened).
    No change for FULL/HALF users — they keep 0.4 as before. SMALL is the
    only AP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
    [clamshell_full.step, clamshell_half.step, clamshell_half.stl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]
2026-05-26 clasp_clearance: scale linearly with knuckle diameter (Po) (#10)
    You confirmed the print: SMALL with the size-aware 0.2 mm clasp clearance
    prints cleanly and the axial play feels right. The next step you asked
    for: drop the SMALL-vs-HALF/FULL binary and scale the clearance with the
    actual knuckle diameter instead.
    Previous formula:
    Cc = 0.2 if knuckle is SMALL else 0.4
    New formula:
    Cc = clamp(0.04 * Po, 0.2, 0.4)
    I.e. linear interpolation from 0.2 mm at Po = 5 mm (your tested SMALL
    case) to 0.4 mm at Po ≥ 10 mm (HALF/FULL territory at typical case_h).
    Clamped on both ends.
    Effect at common configs:
    case_h variant Po Cc (was) Cc (now)
    ----- ------- ---- -------- --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
    [clamshell_full.step, clamshell_half.step, clamshell_half.stl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]
2026-05-26 Make pivot_z_offset a first-class HingeParams parameter (#9)
    * Add pivot_z_offset as a first-class HingeParams parameter
    The empirical 0.2 mm lift was previously a leaky abstraction: it lived
    only as PIVOT_Z_OFFSET in the clamshell example, applied externally by
    passing case_h = WALL_H + PIVOT_Z_OFFSET. Every case designer had to
    re-discover the lift and re-apply it themselves.
    Make it a real parameter on HingeParams with the same default 0.2 mm.
    Internally:
    - The effective leaf height grows by pivot_z_offset so the bed-side
    end of the leaf still reaches the bed when the lifted axis is
    positioned at case_h.
    - The whole hinge body is translated up by pivot_z_offset so the
    le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
    [clamshell_full.step, clamshell_full.stl, clamshell_half.step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]
2026-05-26 examples/clamshell: give magnet pocket 0.1 mm radial clearance (#11)
    The previous code used pocket radius = magnet radius (zero clearance),
    which printed too tight for the magnets to slide in. 0.1 mm radial
    clearance (= 0.2 mm on diameter) is enough on a typical 0.4 mm-nozzle
    FDM — the issue was just needing it to be non-zero, not loose.
    Pocket now sized as ``MAGNET_OD/2 + POCKET_RADIAL_CLEARANCE`` with
    POCKET_RADIAL_CLEARANCE = 0.1 mm. Depth gets a matching 0.1 mm margin
    so the magnet sits flush without binding.
    Variable naming cleaned up while in there: MAGNET_R / MAGNET_D (where
    D meant "depth" but reads as "diameter" everywhere else) →
    MAGNET_OD, MAGNET_T, POCKET_R, POCKET_DEPTH, P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
    [clamshell_full.step, clamshell_half.step, clamshell_half.stl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]
2026-05-26 Make pip-hinge an installable Python package (#12)
    Before: pyproject.toml carried [tool.uv] package = false, so the project
    was a "script project", not an importable library. Downstream consumers
    either had to vendor hinge.py into their own tree (what gramel does) or
    set up a sys.path hack — neither of which lets pip install + import
    work cleanly.
    After: standard src-layout package. Anyone can:
    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
    [clamshell_full.step, clamshell_half.step, clamshell_half.stl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]
2026-06-25 Run the knuckle support ramp tangent to the disc (fixes meshing-side sag)
    The support ramp went from the wall foot straight to the bottom of the knuckle
    circle (0, -T) -- a RADIAL meeting, not a tangent. That leaves the circle's
    underside on the meshing side (the side with no wall) hanging past the contact
    point, so it sags when the print-in-place hinge is printed without supports
    (and prints partly fused, which made the hinge stiff and crack on first fold).
    Run the ramp up TANGENT to the circle instead: from the wall foot to the far
    tangent point, with the disc arc starting there. Each knuckle becomes a
    self-supporting teardrop that cradles the whole underside. SMALL/HALF use the
    tangent r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
2026-06-25 Enforce a self-supporting ramp: tangent >= 45° or raise (no sagging hinge)
    Adversarial review of the tangent fix found it regressed big-disc knuckles: the
    tangent is the steepest ramp that reaches the disc, so for HALF (Ro = case_h/2)
    it comes out ~36° from horizontal -- worse than the old ~43° and well under 45°,
    i.e. it sags. SMALL (small disc) is fine (>= 45°).
    Make it a hard contract: build a tangent ramp only when it is >= 45° from
    horizontal (self-supporting); otherwise raise ValueError naming the angle and
    suggesting Knuckle.SMALL or FULL. No configuration silently produces a hinge
    that needs support. FULL (disc on the bed) is unchanged.
    Sweep (case_h 4-50, all knuckles, mount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
2026-06-25 HALF: self-supporting teardrop knuckle, plus a test suite
    The HALF knuckle previously raised when its foot-anchored tangent ramp came
    out shallower than 45deg from horizontal (the disc is too big for the wall to
    reach steeply). Replace the raise with a teardrop: the support line meets the
    disc TANGENTIALLY on the meshing side at exactly the self-support angle and
    runs down to its own bed contact, so the disc's downward arc is cradled by a
    45deg face instead of left hanging. SMALL keeps the foot-anchored ramp; FULL
    still rests the disc on the bed. Refactored both leaves through one
    _leaf_profile() helper so the wall/underside/arc construction is shared.
    Add tests/ (the package had none): bui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
2026-06-25 Reject mounting_flat<=0; tighten build test to connectivity
    Adversarial review follow-ups:
    - mounting_flat=0 made W==Ro, a degenerate profile OCC rejected with a cryptic
    StdFail_NotDone. Reject it up front (<=0) with a clear ValueError. The 0.5
    default and all in-case use are unaffected.
    - test_builds_valid asserted only 'len(solids) >= 2', which the fragmented pile
    a too-small mounting_flat produces would pass. CASES all use
    mounting_flat=1.0 > pivot_clearance, so each leaf must be one connected body:
    assert exactly 2 solids. Add test_bare_hinge_fragments_below_pivot_clearance
    to LOCK the intentional sub-threshold fragmentation (documented in
    examples/clamshell.py:_split_hin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
2026-06-25 Release v0.3.0: self-supporting teardrop HALF knuckle + test suite
    Minor bump from 0.2.0: adds the HALF teardrop knuckle (tangent meet at
    45deg, self-supporting at any case_h), the first test suite (28 tests),
    and mounting_flat<=0 validation.
2026-06-26 Add PyPI OIDC Trusted Publishing workflow; slim the sdist
    Publish to PyPI on each GitHub Release via OIDC Trusted Publishing
    (pypa/gh-action-pypi-publish) -- no API token stored in the repo. A
    two-job build->publish split runs the publish step in a protected 'pypi'
    environment with id-token: write. workflow_dispatch allows the first
    publish to be triggered manually once the PyPI pending publisher exists.
    Also exclude examples/*.{stl,step} from the sdist: those are generated
    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
2026-09-27 Address #16 feedback: placed output, named leaves, joints, flush leaves
    - New PrintInPlaceHinge(Compound) class with keyword args, in the
    bd_warehouse style; make_hinge(HingeParams) now builds one.
    - Output is placed for a case on the bed: bed at Z=0, wall top at
    case_h, axis at case_h + pivot_z_offset, leaf outer faces at
    X = +/-leaf_width (exposed as hinge.leaf_width / hinge.axis_z).
    - Leaves are labelled children, hinge.cylinder_side / hinge.pin_side,
    grouped correctly even when a bare leaf fragments; replaces the
    example-only _split_hinge_by_side helper.
    - RevoluteJoint/RigidJoint "pivot" on the leaves (0 = flat-open,
    180 = closed).
    - pivot_z_offset now raises only the knuckl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
    [clamshell_full.step, clamshell_full.stl, clamshell_half.step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]
2026-09-27 Add "mount" RigidJoints on each leaf's outer face
    Lets a case wall with a joint place the cylinder-side leaf via
    connect_to, with the pin side following through the pivot joint.
2026-09-27 Include pivot_z_offset in knuckle sizing and wall-gap formulas
    The knuckle is sized to case_h + pivot_z_offset, so the flat-open wall
    gap is Po + 2 * mounting_flat. The README table and integration guide
    omitted the offset, and the SMALL gap formula was wrong outright
    (11 mm documented vs 6.1 mm built at case_h=10).
2026-09-27 Address hinge tab fit and add pin strategies
    Use equal-width alternating tabs and a measured axial clearance. Add conical, rounded, and experimental bridged pins with validation for wall thickness and overall length. Refresh docs, diagrams, generated examples, and packaging for 0.3.0.
    [clamshell_full.step, clamshell_full.stl, clamshell_half.step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]
2026-09-28 Add two-size conical clamshell test plate
    Export small and large print-in-place cases individually and as a spaced plate. Document slicer setup and fit checks, and keep generated meshes out of the source package.
    [conical_clamshell_large.step, conical_clamshell_large.stl, conical_clamshell_pair.step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]
2026-09-28 Use SMALL knuckles on both conical test cases
    Regenerate individual and combined STEP/STL outputs and update print dimensions.
    [conical_clamshell_large.step, conical_clamshell_large.stl, conical_clamshell_pair.step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]
2026-09-28 Add tighter fit clamshell print trial
    Use 0.2 mm radial clearance on both cases and 0.2 mm axial clearance on the small case, following print feedback. Preserve known-working baseline exports for comparison.
    [conical_clamshell_large.step, conical_clamshell_large.stl, conical_clamshell_pair.step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]
2026-09-28 Add tested tight fit profile for small conical hinges
    Keep standard clearances by default. Use a narrow opt-in heuristic matching the successful two-size print trial, preserve explicit overrides, and document the fit choice.
2026-09-28 Keep conical tips separate and clarify package docs
    [clamshell_full.step, clamshell_full.stl, hinge_full.step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]
2026-10-01 Prototype shaped bores for conical and bridged pins
    [clamshell_full.step, clamshell_full.stl, clamshell_half.step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]
2026-10-01 Document shaped-bore print results
2026-10-01 Correct printed trial notes and preview links
2026-10-01 Add reproducible shaped-bore print pair script
2026-10-01 Use platform-neutral print command
2026-10-01 Document P1S print evidence and hinge terminology
